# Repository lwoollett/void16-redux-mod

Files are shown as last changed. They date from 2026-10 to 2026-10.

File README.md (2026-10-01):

# void16-redux-mod

A heavily modified [VOID16](https://github.com/victorlucachi/void16) — 4×4 handwired
macropad with two EC11 encoders, an SSD1306 OLED, a **real topology-optimised**
base, and a nice!nano v2 running ZMK.

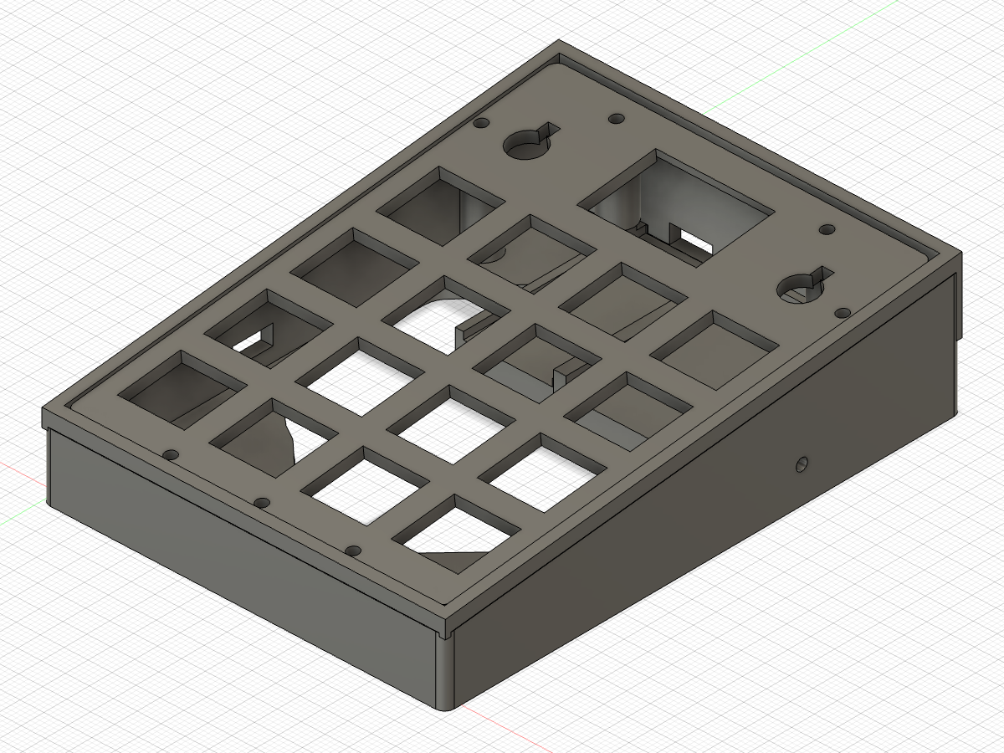
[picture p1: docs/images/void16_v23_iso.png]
iso


---

## What it is

| | |
|---|---|
| Layout | 4×4 MX grid (19.05mm pitch) + 2× EC11 encoders flanking an OLED window |
| Controller | nice!nano v2 (nRF52840, BLE, USB-C charging) |
| Display | SSD1306 I²C OLED, 128×32 (0.91"/0.96") |
| Battery | 402030 LiPo 200mAh (charges via USB-C) |
| Case | 3D printed, 114 × 84.45mm, 6° wedge profile, two parts |
| Firmware | ZMK (`firmware/`), 2 layers + encoder behaviours + OLED status |

### Design highlights

- **Topology-optimised base** — a real SIMP solver (2D density method, ~135
  iterations) ran on the actual load case: seven post loads transferred to the
  side-wall supports, wall band and post pads locked as non-design solids.
  Compliance dropped **208.6 → 36.77 (5.7× stiffer)** at 32% volume fraction.
  The converged field was extracted as one simply-connected smooth void
  (no floating islands → prints support-free), spline-fitted, cut with a 4°
  taper and a flowing inset top-step for the generative "sweep" finish.
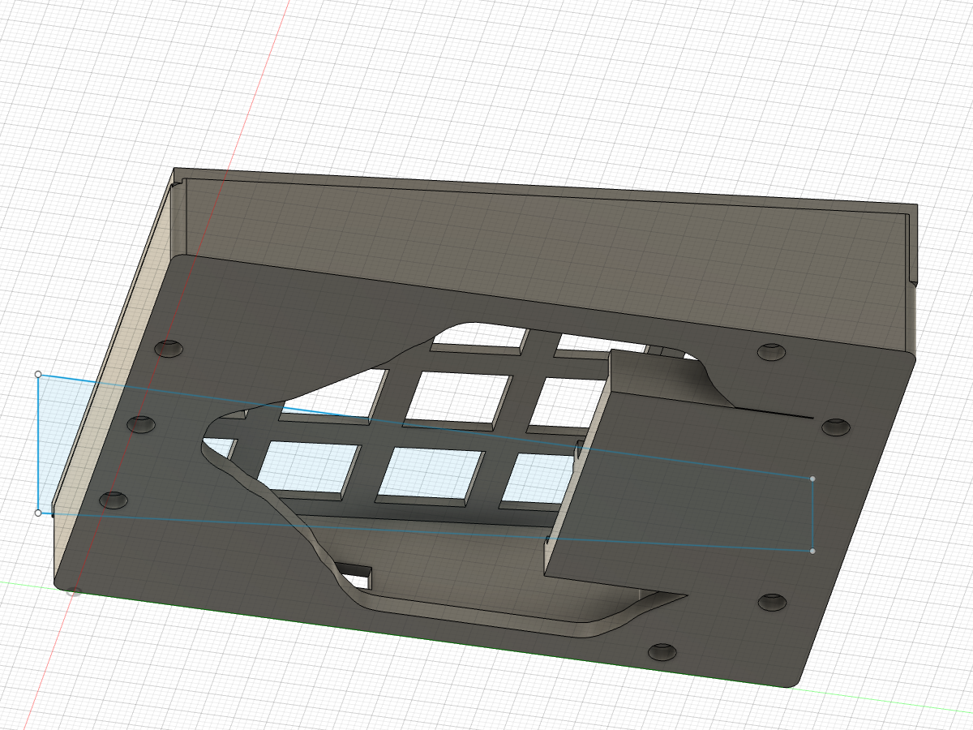
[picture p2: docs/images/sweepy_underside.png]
underside
  
- **Recessed top plate** — 2.5mm plate (MX-clip compatible) drops into a 3mm
  lip collar, captured on all edges, clamped by **7 bottom-up M2 heat-set
  posts** (nothing visible on the plate top).
- **Centred MCU + battery module** — nice!nano pedestal with side guides and a
  same-length, same-height battery tray (PCB and battery rest at z=4.5).
- **Hardware details** — power-switch slot in the left wall, Ø2.5 reset
  pinhole in the right wall (paperclip reset; double-press = bootloader),
  USB-C cutout in the back wall, OLED window with a 3.5mm bezel reveal and
  1mm component-relief channels above and below the screen.
- **MCU relief** — the back-left post corner is relieved to z=9.5 (+1mm over
  the USB-C port) so the nice!nano drops in without touching the TO structure.

### Version history (condensed)

| Ver | Change |
|---|---|
| v1–v5 | 1.5→…→3/4mm thinner plate, centring, pin slot +1mm, LCD bezel + channels |
| v6 | interior posts removed (switch-PCB interference) → perimeter heat-sets |
| v8–v13 | voronoi base (random → hex → stress-graded), centre-support experiments |
| v14 | **real SIMP topology optimisation** replaces all lattice work |
| v16–v17 | centred MCU+battery module, synced trays (same length/height) |
| v18 | sweepy TO finish: spline contour, 4° taper, inset top-step |
| v20 | wall windows reverted; plate 1.5→2.5mm, collar 2→3mm |
| v21 | base sliver fix (clearance = exact pad blanket) |
| v22 | switch slot −0.1mm; reset pinhole added |
| v23 | MCU relief (post corner → z 9.5), top plate frozen |

---

## Gallery

| | |
|---|---|
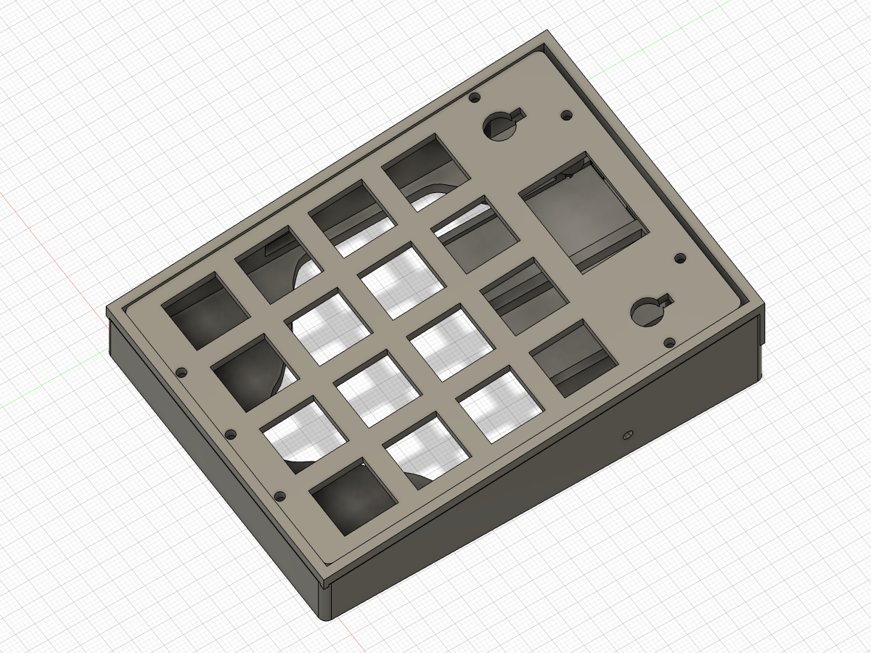
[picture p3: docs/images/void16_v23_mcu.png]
mcu
| iso |  |
| *v23 assembly — TO base, recessed plate, centred module* | *MCU zone — relief cut, pedestal + battery bay* |
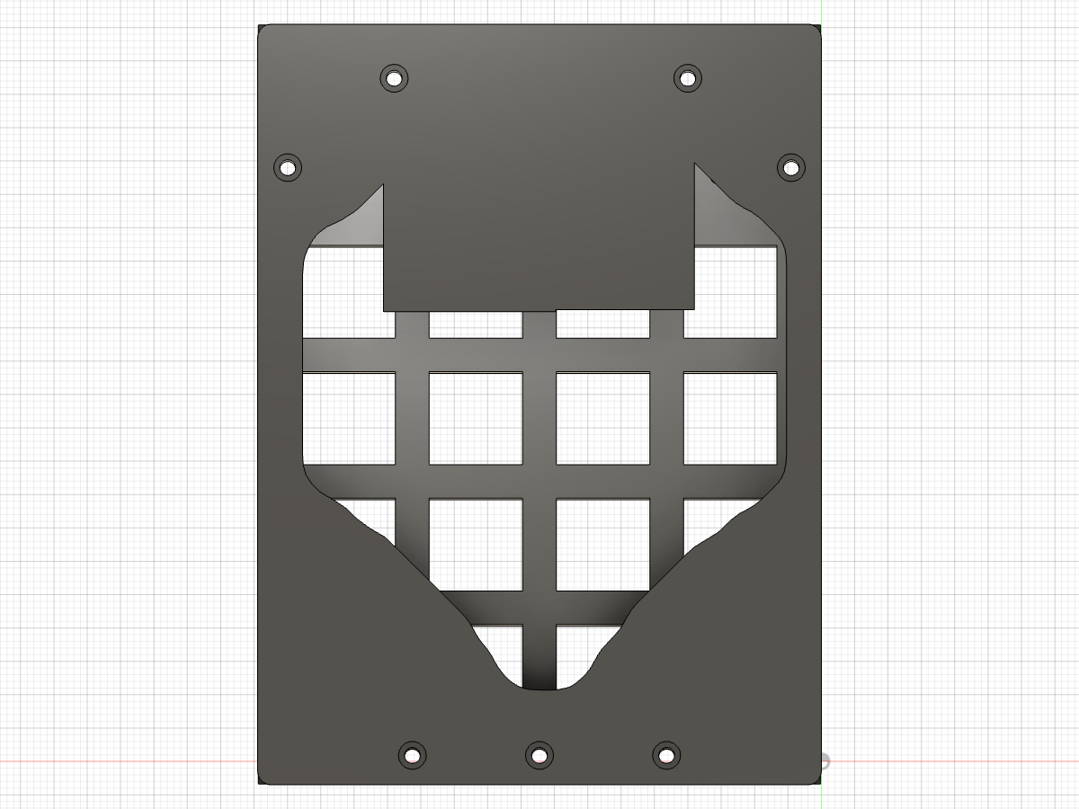
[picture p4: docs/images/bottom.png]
bottom
|  | sweepy |
| *Underside — SIMP-optimised web* | *Sweepy finish: splines, 4° taper, top-step* |
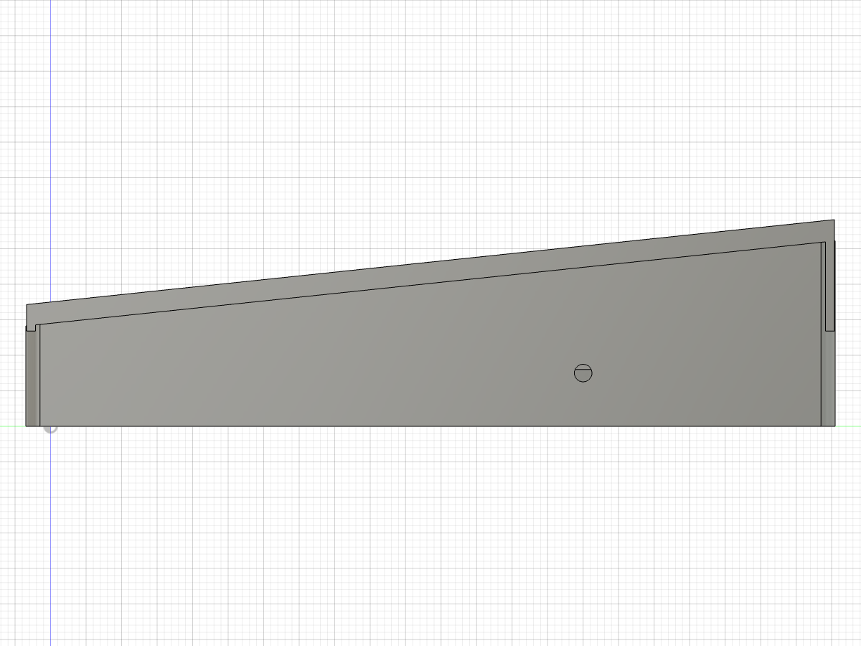
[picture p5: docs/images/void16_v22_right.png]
right
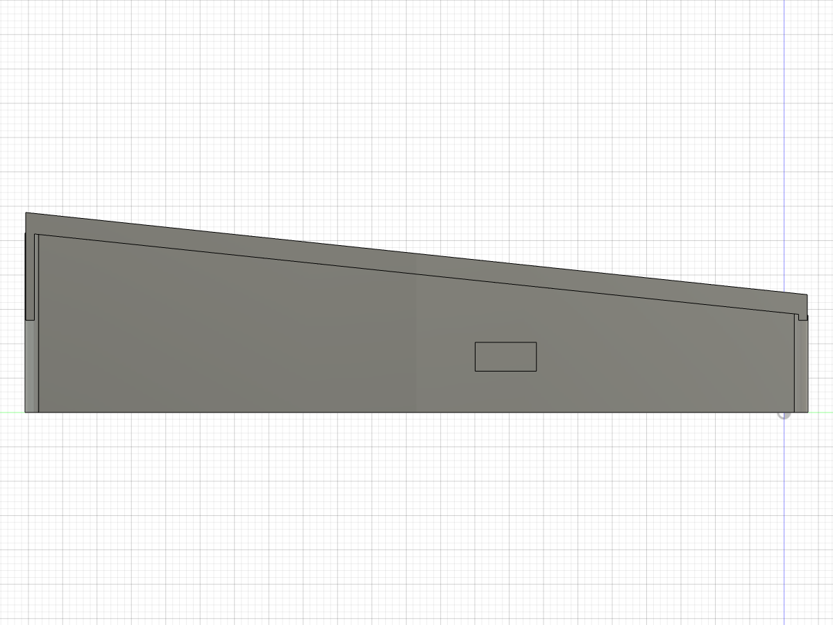
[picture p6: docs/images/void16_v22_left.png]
left
|  |  |
| *Right wall — reset pinhole (y75)* | *Left wall — power-switch slot* |
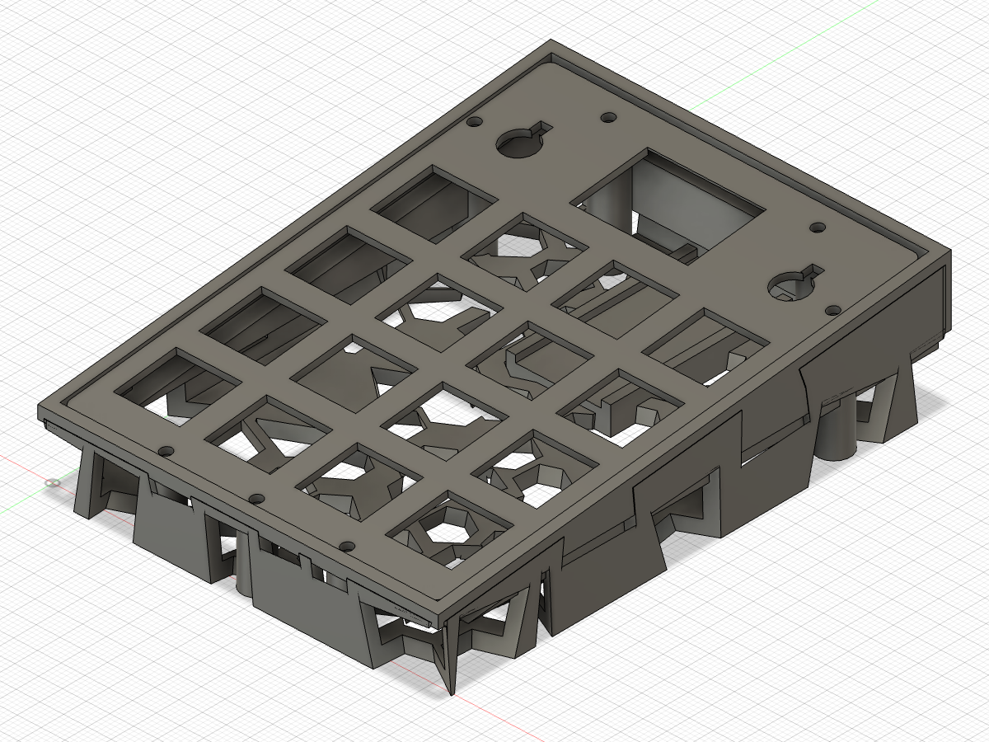
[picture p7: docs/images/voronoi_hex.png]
hex
|  | |
| *v12 — the hex-voronoi era (superseded)* | |

---

## Variants

**Voronoi base** — the same v23 everything (2.5mm plate, 7 posts, centred
module, MCU relief, reset pinhole), with the TO web swapped for a hex-voronoi
lattice (jittered triangular seeds, 2.5mm web, per-cell tilt). For when you're
feeling nostalgic.

| | |
|---|---|
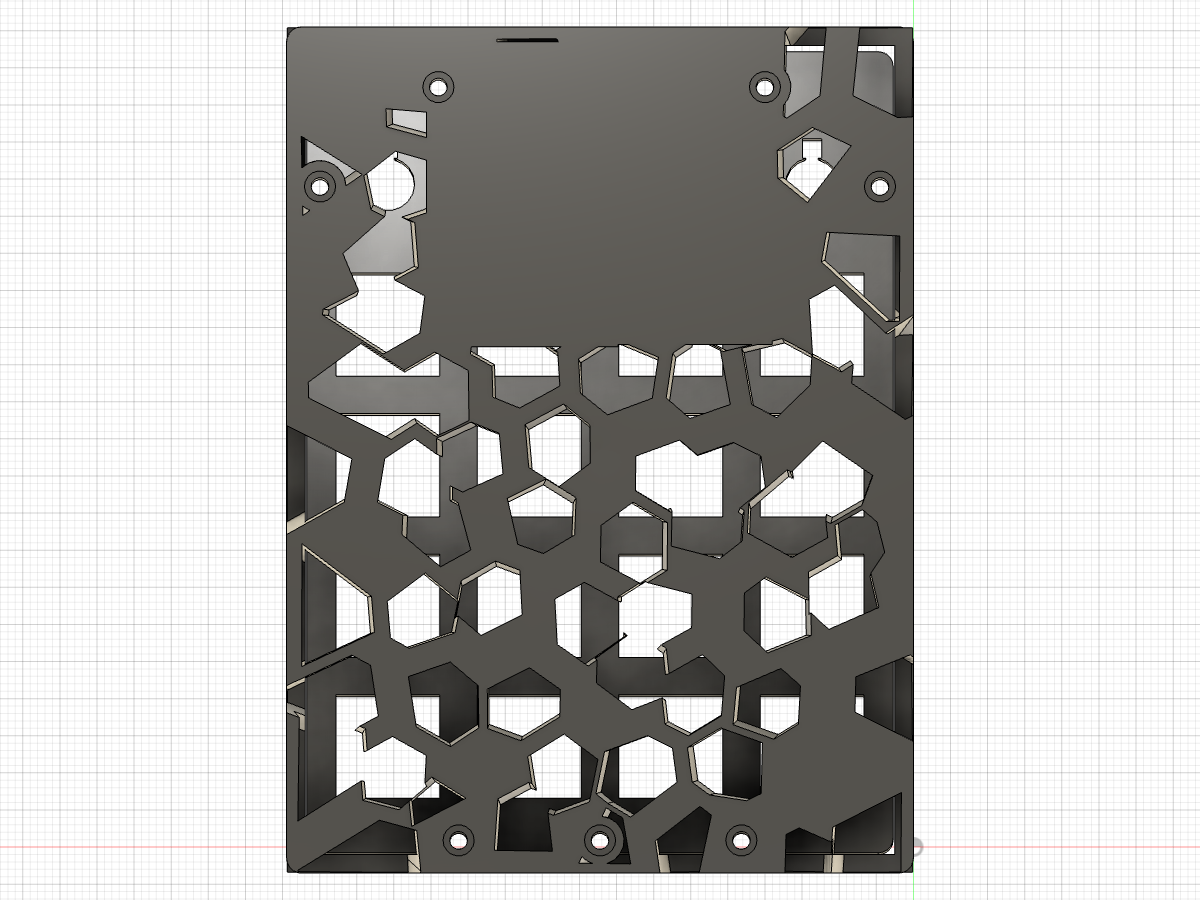
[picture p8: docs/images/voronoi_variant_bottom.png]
vbottom
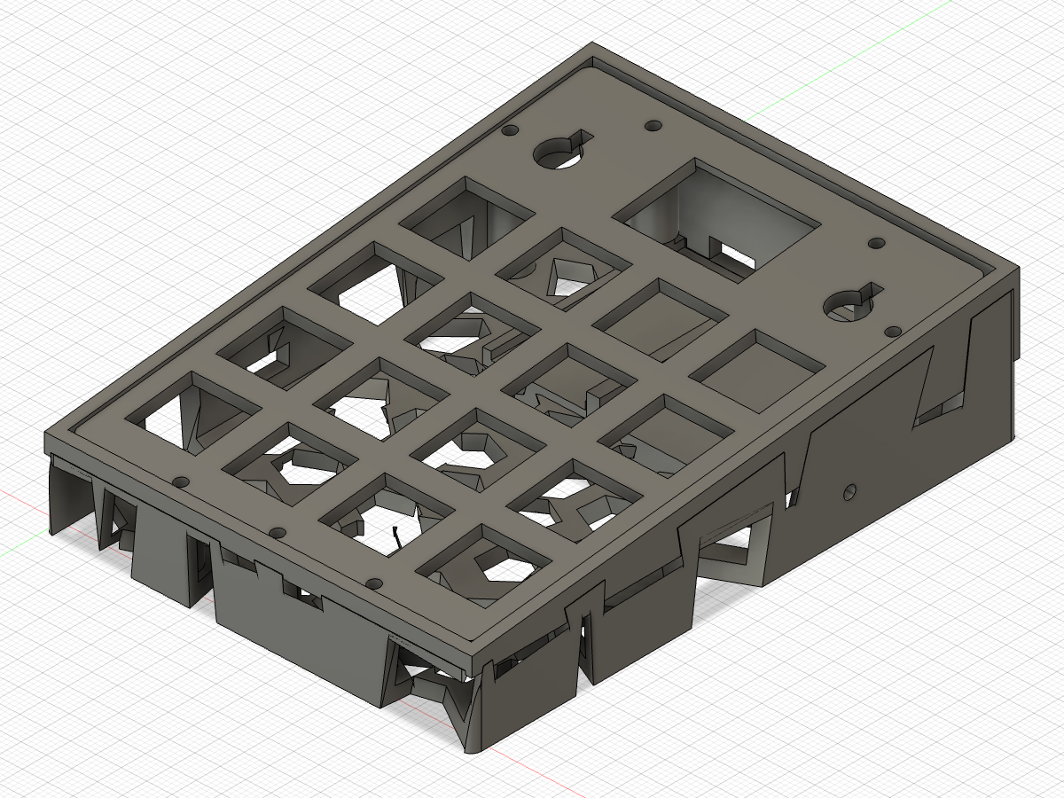
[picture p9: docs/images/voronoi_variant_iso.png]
viso
|  |  |
| *Voronoi variant underside* | *Voronoi variant assembly* |

Files: `cad/bottom-plate-voronoi.stl`, `cad/void16-redux-mod-voronoi.step`,
`cad/void16-redux-mod-voronoi.f3d`, rebuild script
`cad/v24_voronoi_rebuild.py`. Bottom is ~38.9 cm³ (vs 44.4 TO — the hex web
is sparser). Top plate, coupon and firmware are identical — only the bottom
STL changes when printing this variant.

---

## Bill of materials

### Printed parts (`cad/`)
| Part | File | Notes |
|---|---|---|
| Bottom | `bottom-plate.stl` | print floor-down, no supports |
| Top plate | `top-plate.stl` | print flat; 2.5mm — test MX clip bite on a scrap first |
| Fit coupon | `screen-encoder-slice.stl` | screen/encoder/gap test slice — print before committing |

### Hardware
| Part | Spec | Qty |
|---|---|---|
| Heat-set inserts | M2×4 brass | 7 |
| Screws | M2×25 socket (4 tall posts) / M2×14 (3 front posts) | 7 |
| Switches | MX, on per-switch PCBs w/ 1N4148 | 16 |
| Keycaps | any | 16 |
| Encoders | EC11 plate-mount | 2 |
| OLED | SSD1306 I²C 128×32 | 1 |
| Controller | nice!nano v2 | 1 |
| Battery | 402030 LiPo 200mAh w/ PCM | 1 |
| Power switch | MSK-12C02-family SPDT slide | 1 |
| Reset button | 6×6×5h horizontal tactile w/ bracket | 1 |
| Wire | 24AWG buses / 26AWG signals | ~2m |

Full wiring diagram + firmware guide: **[`firmware/WIRING.md`](firmware/WIRING.md)**.

---

## Printing & assembly

1. Print all three parts (0.4mm nozzle; the TO base is support-free by
   construction). Test-fit switches and the LCD/encoders on the coupon.
2. Press 7 heat-set inserts into the post tops (iron from inside the case).
3. Handwire the matrix per `firmware/WIRING.md` (diode stripe → ROW bus),
   wire encoders, OLED, power switch (series with battery +), reset button
   (RST→GND behind the right-wall pinhole).
4. Drop the nice!nano into the pedestal guides (USB-C through the back slot),
   battery into the bay, wires across the web (hot-glue down).
5. Flash (see below), test, then seat the plate into the collar and drive the
   seven M2 screws from underneath.

## Firmware

`firmware/` is a self-contained ZMK config (also usable standalone — see its
own `WIRING.md`):

```
cd firmware
./build.sh                    # → staged-zmk.uf2
# double-tap reset (pinhole ×2) → NICEBOOT drive appears
cp staged-zmk.uf2 /Volumes/NICEBOOT/ && diskutil eject NICEBOOT
```

Default layers: **0** numpad + FN hold · **1** F1–F16. Encoder L = volume /
pgup-pgdn, encoder R = track / home-end. OLED shows battery/output/layer.

A prebuilt `staged-zmk.uf2` is committed for first flash.

## Repository layout

```
cad/                     printable STLs, STEP, native .f3d (v23)
cad/v23_rebuild.py       deterministic Fusion 360 rebuild script (exec via API)
cad/tools/               SIMP solver + converged field JSONs (reproduce the TO base)
firmware/                ZMK config, WIRING.md, prebuilt UF2
docs/images/             renders
```

## Credits

- Original VOID16 design: [victorlucachi/void16](https://github.com/victorlucachi/void16)
- Firmware: [ZMK](https://zmk.dev) · Hardware: nice!nano by Nice Keyboards

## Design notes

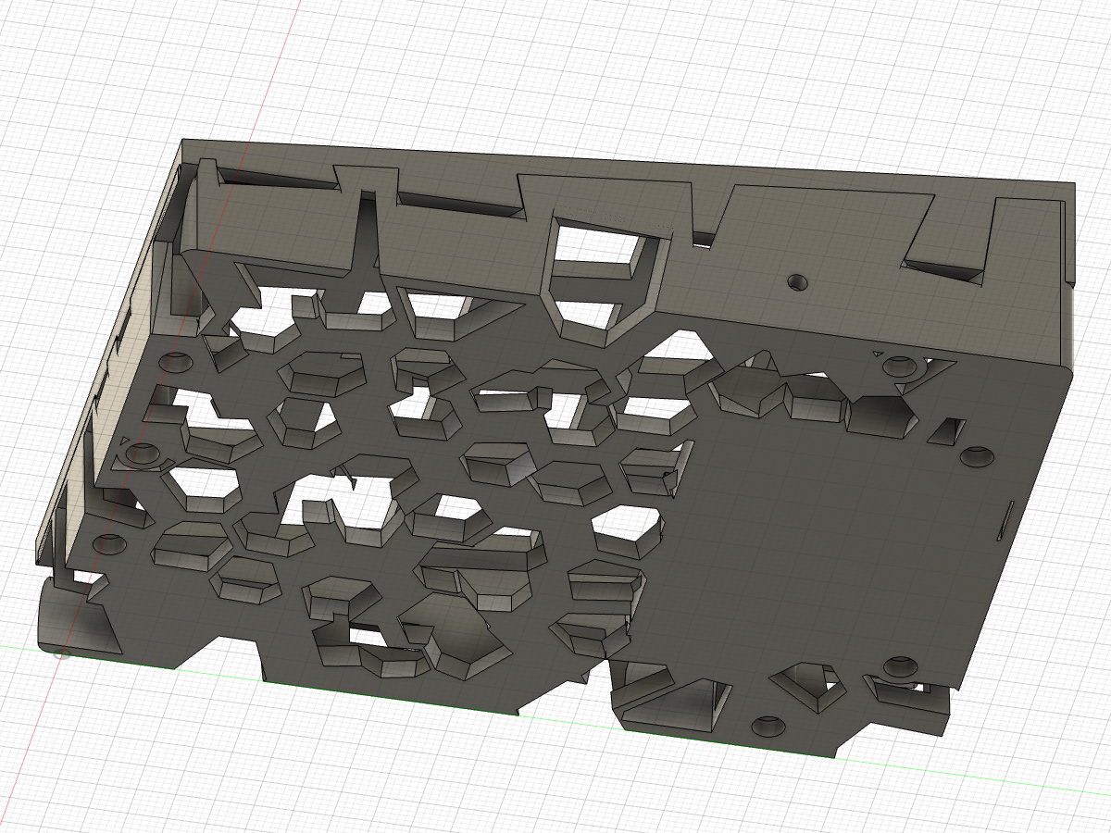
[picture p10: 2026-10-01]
docs/images/voronoi_variant_low.png

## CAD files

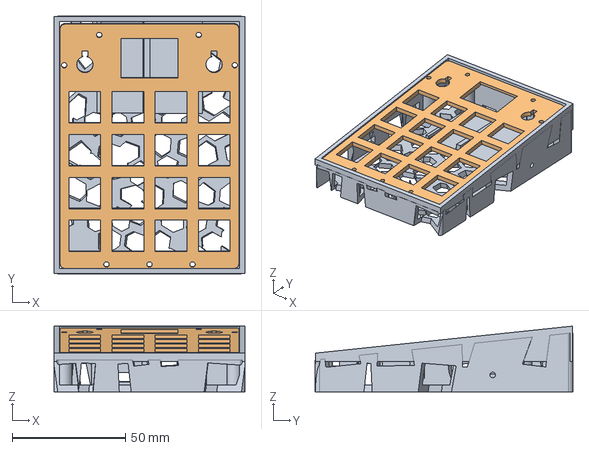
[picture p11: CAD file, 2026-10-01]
cad/void16-redux-mod-voronoi.step
84.5 x 114.0 x 29.1 mm

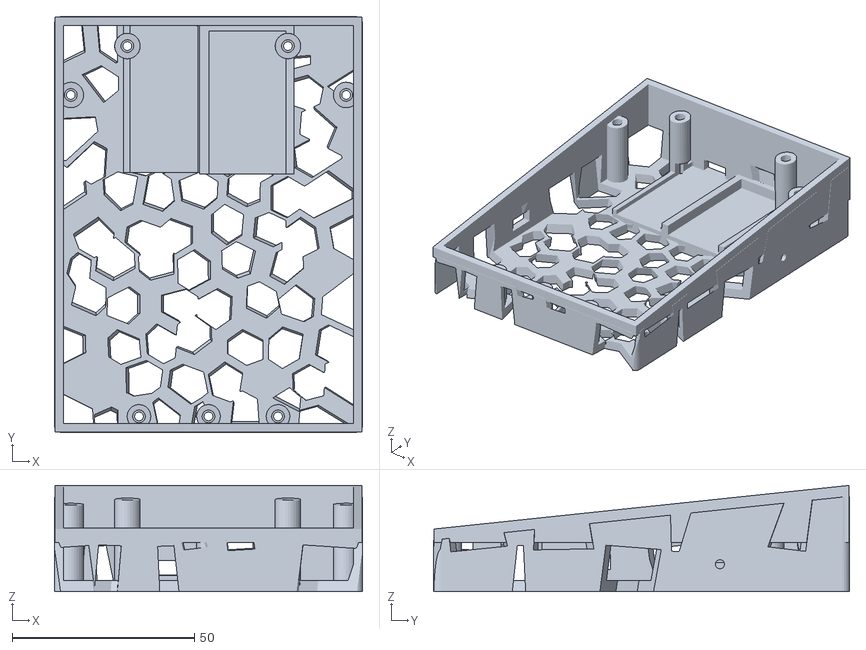
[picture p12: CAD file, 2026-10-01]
cad/bottom-plate-voronoi.stl
84.4 x 114.0 x 29.1

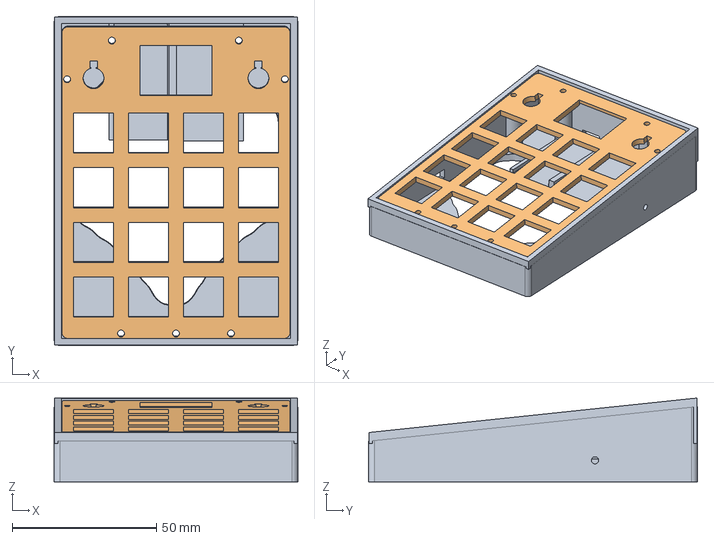
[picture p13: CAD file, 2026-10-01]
cad/void16-redux-mod.step
84.5 x 114.0 x 29.1 mm

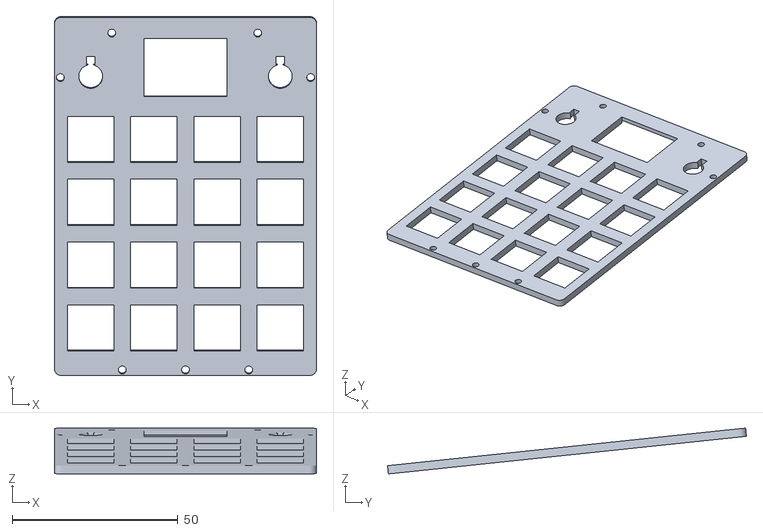
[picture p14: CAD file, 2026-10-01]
cad/top-plate.stl
79.0 x 108.2 x 13.8

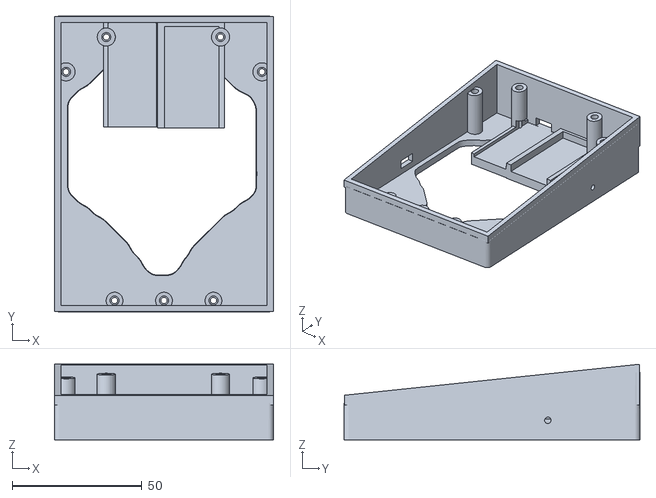
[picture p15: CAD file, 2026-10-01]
cad/bottom-plate.stl
84.4 x 114.0 x 29.1

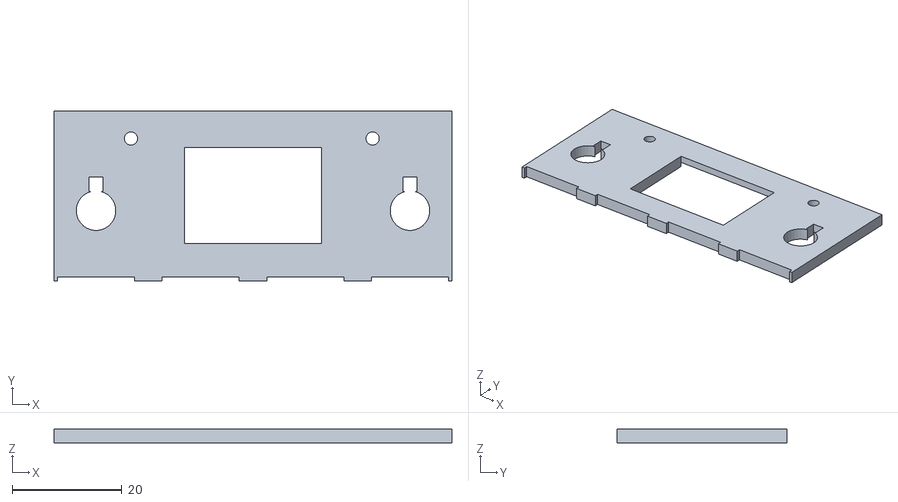
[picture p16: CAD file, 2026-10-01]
cad/screen-encoder-slice.stl
72.4 x 31.0 x 2.50

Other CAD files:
cad/void16-redux-mod-v23.f3d
cad/void16-redux-mod-voronoi.f3d

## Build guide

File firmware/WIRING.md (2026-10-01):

# void16-redux-mod — Wiring & Firmware Guide

Complete build documentation: handwiring, power, enclosure hardware, firmware, flashing.

---

## 1. Bill of electrical parts

| Part | Spec | Qty | Notes |
|---|---|---|---|
| Controller | nice!nano v2 (nRF52840) | 1 | mounts on the pedestal, guides retain it |
| Switch PCBs | per-switch, 1N4148 diode each | 16 | diode stripe (cathode) → ROW wire |
| Encoders | EC11, plate-mount | 2 | flanking the screen; push legs unused |
| OLED | SSD1306 I²C, 0.91"/0.96" | 1 | 128×32 default firmware; 128×64 = 2-line config change |
| Battery | 402030 LiPo 200mAh + protection PCM | 1 | drops in the battery bay from above |
| Power switch | SPDT slide, side-actuator (MSK-12C02 family) | 1 | left-wall slot |
| Reset button | 6×6 horizontal tactile w/ bracket, 5mm actuator | 1 | behind pinhole, right wall (v22+) |
| Wire | 24–26 AWG solid/stranded | ~2m | matrix buses 24AWG, signals 26AWG |

---

## 2. Matrix wiring (col2row)

```
        (viewed from above, USB/encoders at the top, typing position)

     ENC-L                            ENC-R
    A=D1 B=D0                        A=D19 B=D18
     │  │          COL0   COL1   COL2   COL3
     │  │           D8     D9     D10    D16
     │  │            │      │      │      │
     │  │  ROW0 D4 ──┼──7────┼──8───┼──9───┼──÷──┐
     │  │            │      │      │      │      │
     │  │  ROW1 D5 ──┼──4────┼──5───┼──6───┼──×──┐│
     │  │            │      │      │      │     ││
     │  │  ROW2 D6 ──┼──1────┼──2───┼──3───┼───−┐││
     │  │            │      │      │      │    │││
     │  │  ROW3 D7 ──┼──0────┼──.───┼─ENT──┼─FN┐│││
     │  │                                                  ROW bus (4 wires)
     └──┴── GND (ENC commons ×2)                          COL bus (4 wires)
   (numbers = numpad legend of default layer)
```

- Each switch: one leg → its ROW bus wire; other leg (through PCB diode, **stripe→ROW**) → its COL bus wire.
- Run ROW/COL buses through the 5mm gaps between the switch PCB columns, down to the MCU pedestal.
- Dead-key after wiring = one diode backwards (stripe must face the row wire).

## 3. nice!nano v2 pin map

| Function | pro_micro N | nRF GPIO | silk | | Function | pro_micro N | nRF GPIO | silk |
|---|---|---|---|---|---|---|---|---|
| ROW0 | 4 | P0.22 | "4" | | COL2 | 10 | P0.09 | "10" |
| ROW1 | 5 | P0.24 | "5" | | COL3 | 16 | P0.10 | "16" |
| ROW2 | 6 | P1.00 | "6" | | ENC-L A | 1 | P0.06 | "1" |
| ROW3 | 7 | P0.11 | "7" | | ENC-L B | 0 | P0.08 | "0" |
| COL0 | 8 | P1.04 | "8" | | ENC-R A | 19 | P0.02 | "19" |
| COL1 | 9 | P1.06 | "9" | | ENC-R B | 18 | P1.15 | "18" |

- **OLED: SDA=D2 (P0.17), SCL=D3 (P0.20)** — hardware i2c0, the ONLY working pair. VCC→3V3, GND→GND.
- **EC11 encoders**: both COMMON pins → GND. A/B → pins above. Push-switch legs: unused.
- Battery + switch: see power section. All grounds star at the nice!nano GND pins.

## 4. Power wiring

```
 402030 LiPo                          nice!nano v2 (underside)
 ┌──────────┐                         ┌─────────────┐
 │ + (red) ─┼──► pin 2 ── pin 1 ──►──┼ BATT/B2B +  │   slide switch
 │          │        (MSK-12C02)      │             │   in left-wall slot
 │ − (blk) ─┼──────────────────────►──┼ B2B  GND    │
 └──────────┘                         └─────────────┘
```

- SPDT slide: use centre pin + one outer. In series with battery RED only.
- Route: red lead over the bay lip at z≈6, across the cavity to the left-wall switch
  (~45mm), back to BATT. Hot-glue to the web top so it can't sag onto PCBs.
- **Charges only when switch ON** (charger sees battery through it) — leave ON when on USB.
- Reversing battery polarity on B2B pads kills the nice!nano. Check twice, power once.
- Charge current 100mA → ~2h for 200mAh. Over-discharge protection lives in the battery PCM.

## 5. Reset button (v22 case)

- 6×6×5h horizontal tactile with bracket, glued to the inside of the wall behind the
  **Ø2.5 pinhole**, actuator facing the hole.
- Wire: one pin → RST, other → GND on the nice!nano.
- Poke a paperclip through the pinhole to press. **Double-press = bootloader (NICEBOOT
  drive)** — same button, two presses, no disassembly.

## 6. Firmware

Repo: `~/repos/zmk-config-void16/` (flat config, board `nice_nano//zmk`).

```
config/nice_nano.overlay   kscan + encoders + OLED + physical layout
config/nice_nano.keymap    layers (see below)
config/nice_nano.conf      encoder + display Kconfigs
build.sh                   full build → staged-zmk.uf2
```

**Keymap**

| Layer | Grid | ENC-L | ENC-R |
|---|---|---|---|
| 0 (Num) | 7 8 9 ÷ / 4 5 6 × / 1 2 3 − / 0 . ⏎ FN | volume | track |
| 1 (FN) | F13–F16 / F9–F12 / F5–F8 / F1–F4 | pgup/pgdn | home/end |

**Build & flash**
```
./build.sh
# double-tap RST (or the reset pinhole ×2) → NICEBOOT drive
cp staged-zmk.uf2 /Volumes/NICEBOOT/ && diskutil eject NICEBOOT
```

**OLED panel variant**: 128×64 panels → in `config/nice_nano.overlay` set
`height = <64>` and `multiplex-ratio = <63>`, rebuild.

**Adding soft-off instead of the slide switch**: bind `&soft_off` on any key
(deep sleep ≈ 20µA) — ask and it gets added + rebuilt.

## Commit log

2026-10-01 void16-redux-mod v23: TO-optimised case, ZMK firmware, docs
    [bottom-plate.stl, screen-encoder-slice.stl, top-plate.stl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]
2026-10-01 docs: AGENTS.md — agent guidance for CAD rebuild workflow and firmware conventions
2026-10-01 v24 voronoi variant: hex-lattice base on v23 chassis (STL/STEP/f3d, rebuild script, renders, README section)
    [bottom-plate-voronoi.stl, void16-redux-mod-voronoi.f3d, void16-redux-mod-voronoi.step]
